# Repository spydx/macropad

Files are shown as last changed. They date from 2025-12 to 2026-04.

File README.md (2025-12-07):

# Macro Pad

This is a small macropad inspired by the Figma Pad from Worklouder Figma Creator.

## v1.1

The first version, I did some mistakes and are not entirely happy with it. I managed to wire the OLED wrong, and are not happy with the placement of the microcontroller.

v1.1 contains fixes for:

- OLED Wiring (mixed up SDA & SCL signal)
- Flipped Diode (only on the board)

If you wanna build it, you can follow the instructions in the [README](v1.1/README.md)

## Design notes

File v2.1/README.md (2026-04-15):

# Macropad v1.1

My first attempt on build a 14 key macropad with two rotary encoders.

Read everything first, this is a very thin guide of what you need, the rest you are on your own.

## What you need

| Count | Component | Link |
| ---- | --- | --- |
|  1 | PCB | JLCPCB or any other |
|  1 | WaveShare RP2040-Zero USB-C| [WaveShare](https://www.waveshare.com/rp2040-zero.htm?sku=20335) |
| 14 | 1N4148 Diodes | [Mouser](https://no.mouser.com/ProductDetail/onsemi-Fairchild/1N4148?qs=i4Fj9T%2FoRm8RMUhj5DeFQg%3D%3D) |
| 12 | Kailh Choc V2 Low Profiles Keys | [Max Gamming](https://www.maxgaming.no/no/switchar/choc-v2-low-profile-brown) |
|  2 | Rotary Encoderss PEC12R-2120F-S0012 | [Mouser](https://no.mouser.com/ProductDetail/Bourns/PEC12R-2120F-S0012?qs=Zq5ylnUbLm4y5zPMmL%252Bc3g%3D%3D) |
|  1 | OLED 128x32 SSD1306 I2C | [Amazon](https://www.amazon.com/128x32-SSD1306-Consumption-Display-Arduino/dp/B07PDFCVXL) |

Notes.. if you buy other parts than these they might not be compatible, inspect the schematics for details if the components will fit.

You will need knobs for the encoders and keycaps, see 3D print section.

## PCB

The [PCB](PCB/production/BouvetMacroPad-Rev2.1.zip) can be used to produce the new Rev 2.1 version of the macropad.

You can get PCBs printed from PCBWay or any other.

## Soldering

Recommended soldering order

- Diodes
- Microcontroller
- Switches
- Rotary Encoders
- OLED

## 3D printed Parts

### Keycaps and Knobs

Keycaps are not mentioned here, but you will need Low Profile Keycaps that fit the Kailh Choc V2.
There are many available to be 3D printed. E.g. the following will fit: [Keycaps](https://makerworld.com/en/models/1152559-choc-v2-ultra-thin-keycaps#profileId-1156967)

Rotary encoder knobs are also needed e.g. [these](https://makerworld.com/en/models/154058-grippy-encoder-knob?from=search#profileId-169689)

### Case

There is a small case, designed by Vilde Holtet, in the [CAD](CAD) folder.

There is a STEP file of the PCB that you can use to aid the design a new case in e.g. FreeCAD.

No special setting, when printing

## QMK Firmware

This keyboard uses QMK, until the my PR has been accepted, you need to follow these special steps.

You need to download MY fork of the repository, and checkout the custom branch `custom-keyboards`.
This contains the handwired keyboard config for the macropad.

```shell
git clone https://github.com/spydx/qmk_firmware
cd qmk_firmware
git checkout bouvetv2

# Ensure that this folder is the QMK homedir
qmk config user.qmk_home=<pwd of your folder> 
qmk config user.keyboard=handwired/bouvet/macropad/v2
qmk config user.keymap=default
```

Once this is you can compile and flash the macropad.

```shell
qmk compile

# While connecting the macro pad, press and hold the top LEFT button until the macropad is detected
qmk flash 
```

Ready to use

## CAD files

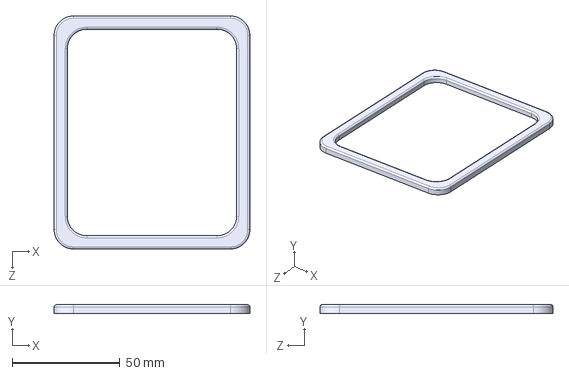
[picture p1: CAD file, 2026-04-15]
v2.1/CAD/Topp (kun frame).STEP
91.0 x 4.00 x 108.3 mm

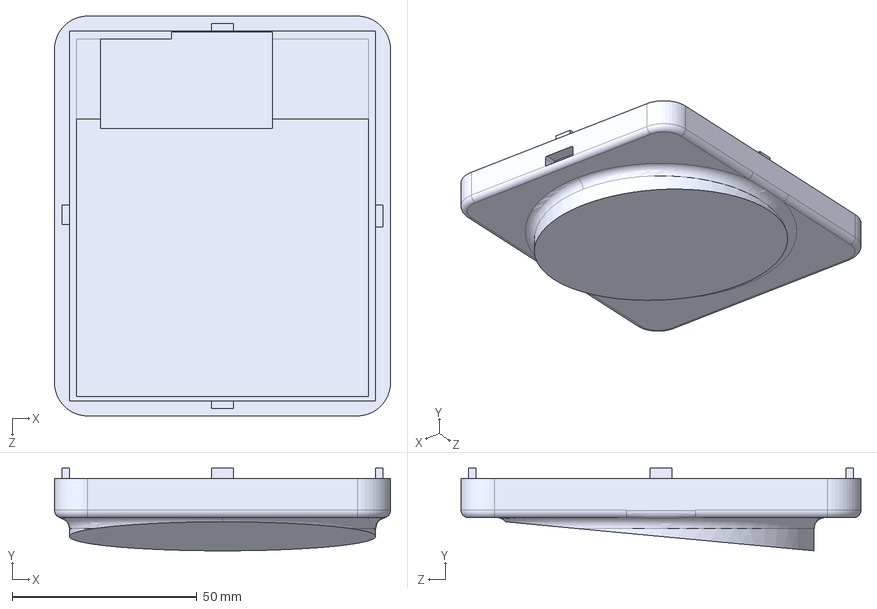
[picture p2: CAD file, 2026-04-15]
v2.1/CAD/Base.STEP
91.0 x 22.4 x 108.3 mm

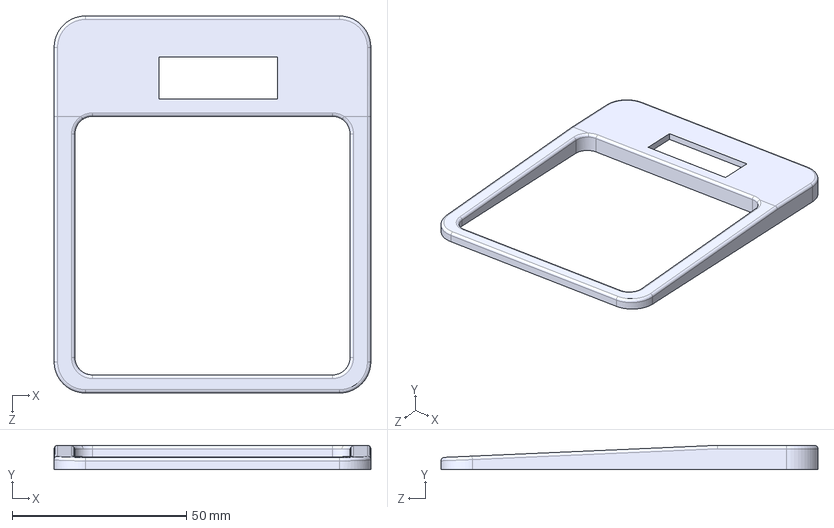
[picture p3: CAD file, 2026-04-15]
v2.1/CAD/Topp (m_ slot for skjerm).STEP
91.0 x 7.00 x 108.3 mm

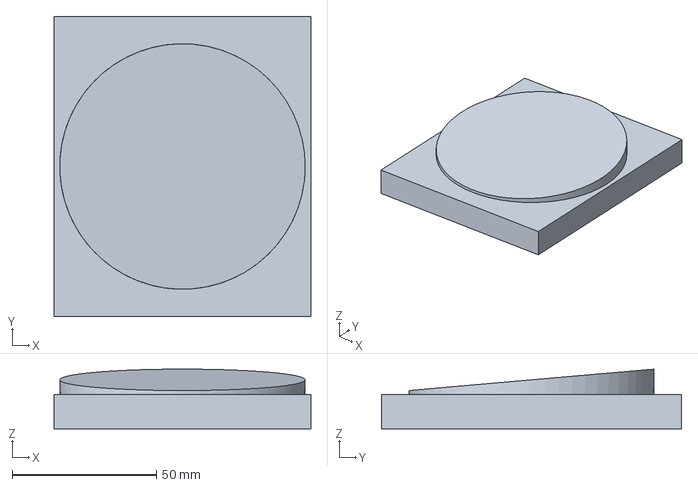
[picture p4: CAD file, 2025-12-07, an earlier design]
v1.1/Cad/MacroPadCase.FCStd
89.0 x 104.0 x 20.7 mm

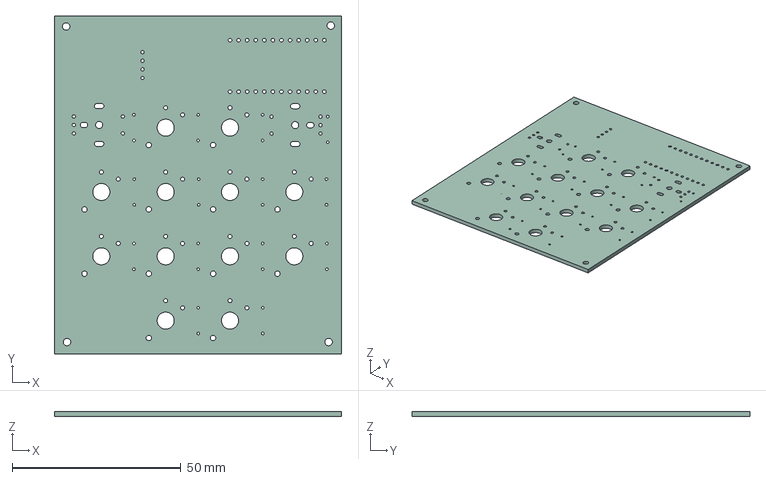
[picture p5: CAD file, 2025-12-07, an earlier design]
v1.1/Cad/Figma_KeyPad_PCB.step
85.0 x 100.0 x 1.51 mm

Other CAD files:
v1.1/Cad/MacroPadCase.stl

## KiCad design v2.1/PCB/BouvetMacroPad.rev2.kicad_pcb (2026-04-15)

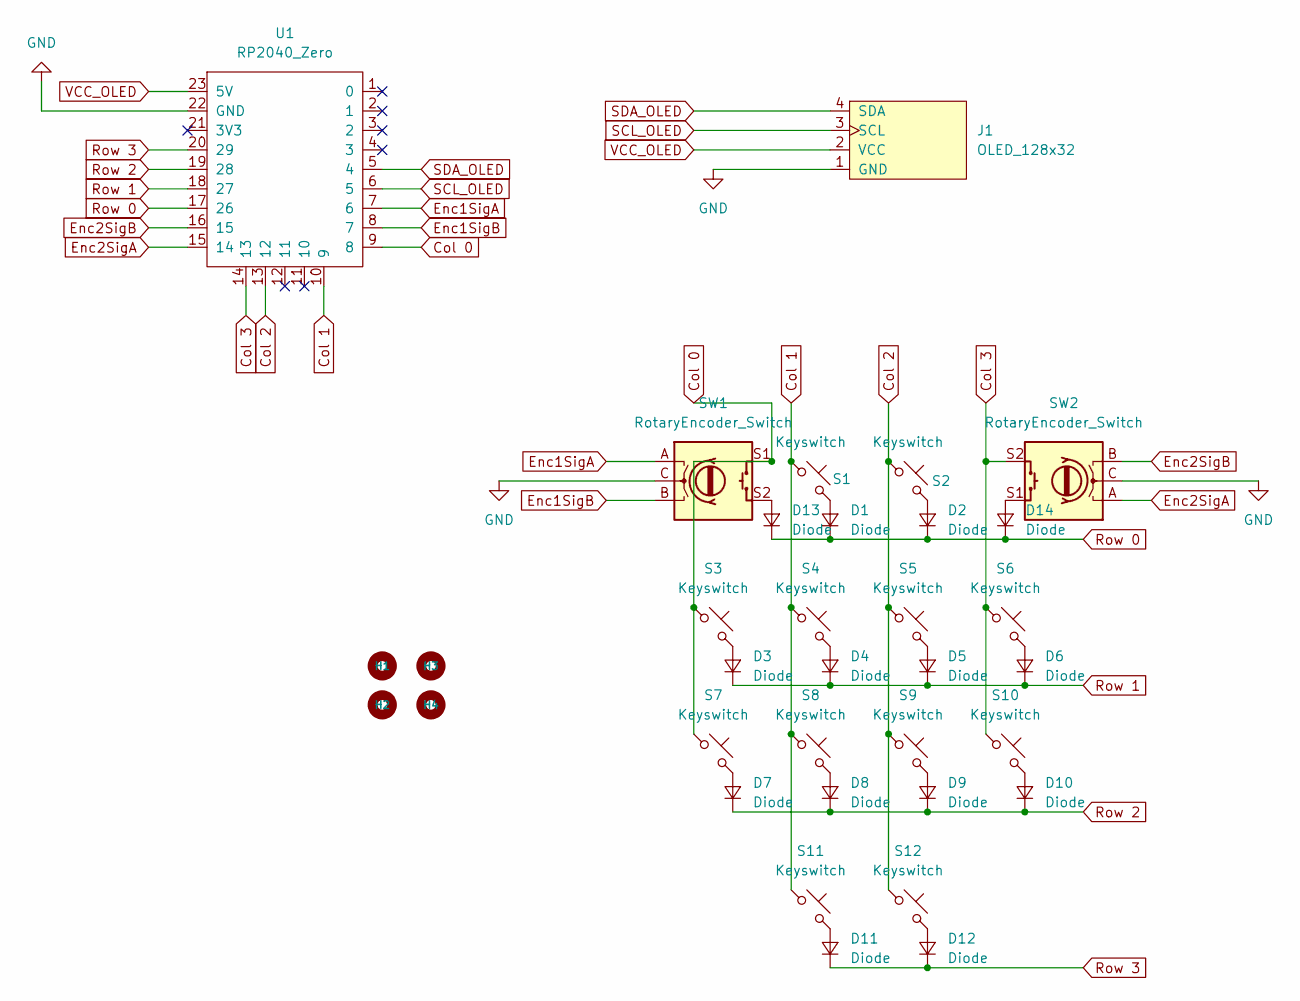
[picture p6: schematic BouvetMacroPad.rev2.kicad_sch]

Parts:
D1, D2, D3, D4, D5, D6, D7, D8, D9, D10, D11, D12, D13, D14: Diode; Diode_DO-35
H1, H2, H3, H4: MountingHole_5mm
J1: OLED_128x32
S1, S2, S3, S4, S5, S6, S7, S8, S9, S10, S11, S12: Keyswitch; Choc_V2_1.00u
SW1, SW2: RotaryEncoder_Switch; RotaryEncoder_Alps_EC11E-Switch_Vertical_H20mm_MountingHoles
U1: RP2040_Zero

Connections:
Col 0: S3.1, S7.1, SW1.S1, U1.9 (8)
Col 1: S1.1, S4.1, S8.1, S11.1, U1.10 (9)
Col 2: S2.1, S5.1, S9.1, S12.1, U1.13 (12)
Col 3: S6.1, S10.1, SW2.S2, U1.14 (13)
Enc1SigA: SW1.A, U1.7 (6)
Enc1SigB: SW1.B, U1.8 (7)
Enc2SigA: SW2.A, U1.15 (14)
Enc2SigB: SW2.B, U1.16 (15)
GND: J1.1 (GND), SW1.C, SW2.C, U1.22 (GND)
unnamed: D1.2 (A), S1.2
unnamed: D2.2 (A), S2.2
unnamed: D3.2 (A), S3.2
unnamed: D4.2 (A), S4.2
unnamed: D5.2 (A), S5.2
unnamed: D6.2 (A), S6.2
unnamed: D7.2 (A), S7.2
unnamed: D8.2 (A), S8.2
unnamed: D9.2 (A), S9.2
unnamed: D10.2 (A), S10.2
unnamed: D11.2 (A), S11.2
unnamed: D12.2 (A), S12.2
unnamed: D13.2 (A), SW1.S2
unnamed: D14.2 (A), SW2.S1
Row 0: D1.1 (K), D2.1 (K), D13.1 (K), D14.1 (K), U1.17 (26)
Row 1: D3.1 (K), D4.1 (K), D5.1 (K), D6.1 (K), U1.18 (27)
Row 2: D7.1 (K), D8.1 (K), D9.1 (K), D10.1 (K), U1.19 (28)
Row 3: D11.1 (K), D12.1 (K), U1.20 (29)
SCL_OLED: J1.3 (SCL), U1.6 (5)
SDA_OLED: J1.4 (SDA), U1.5 (4)
VCC_OLED: J1.2 (VCC), U1.23 (5V)

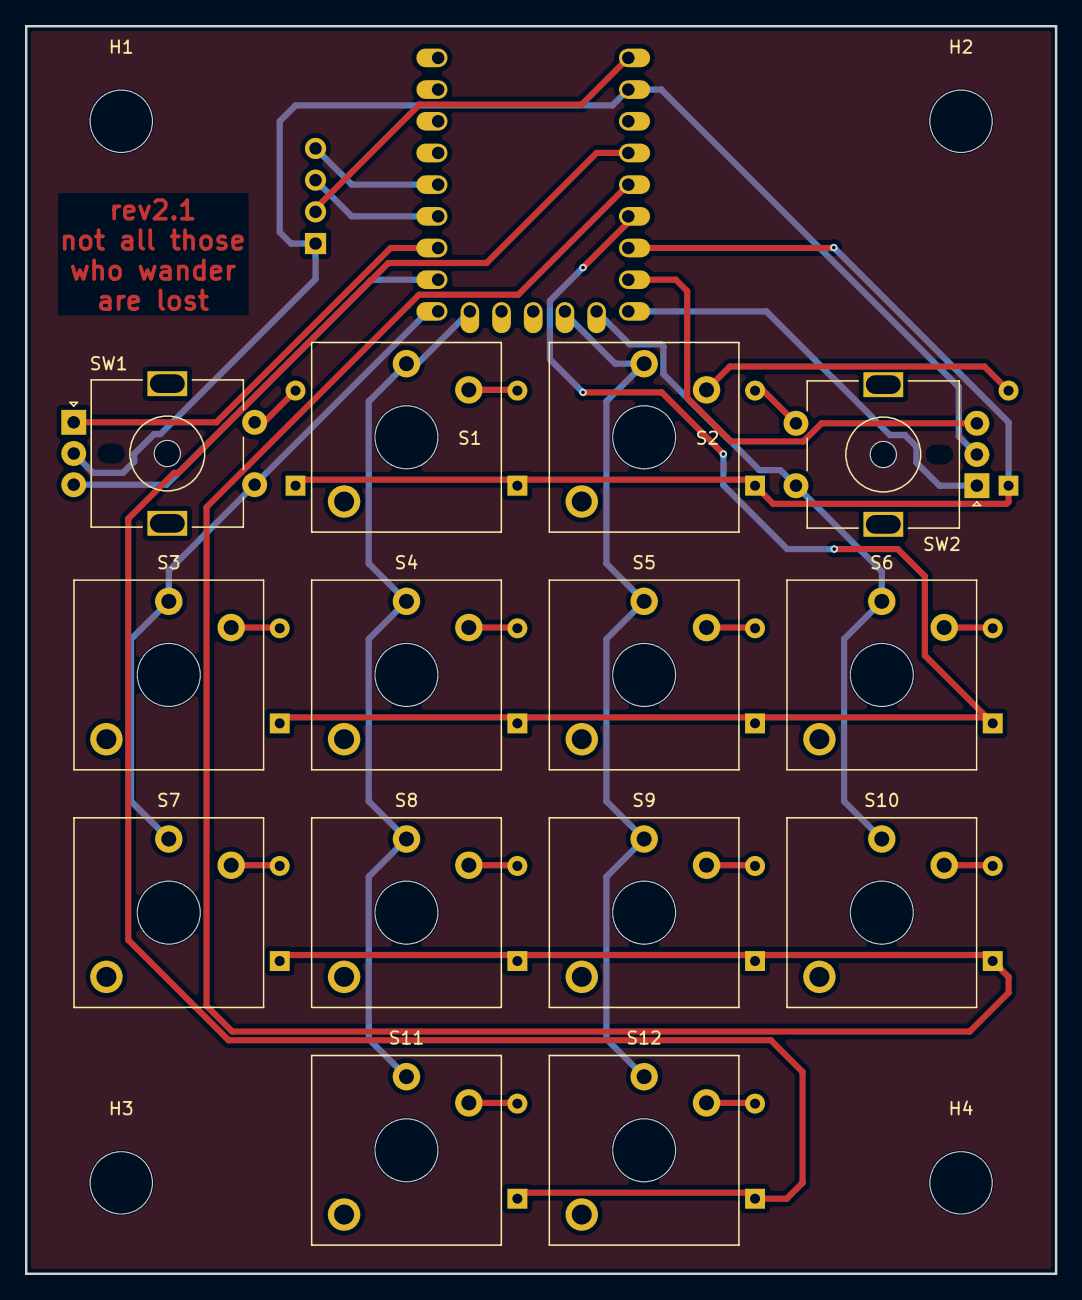
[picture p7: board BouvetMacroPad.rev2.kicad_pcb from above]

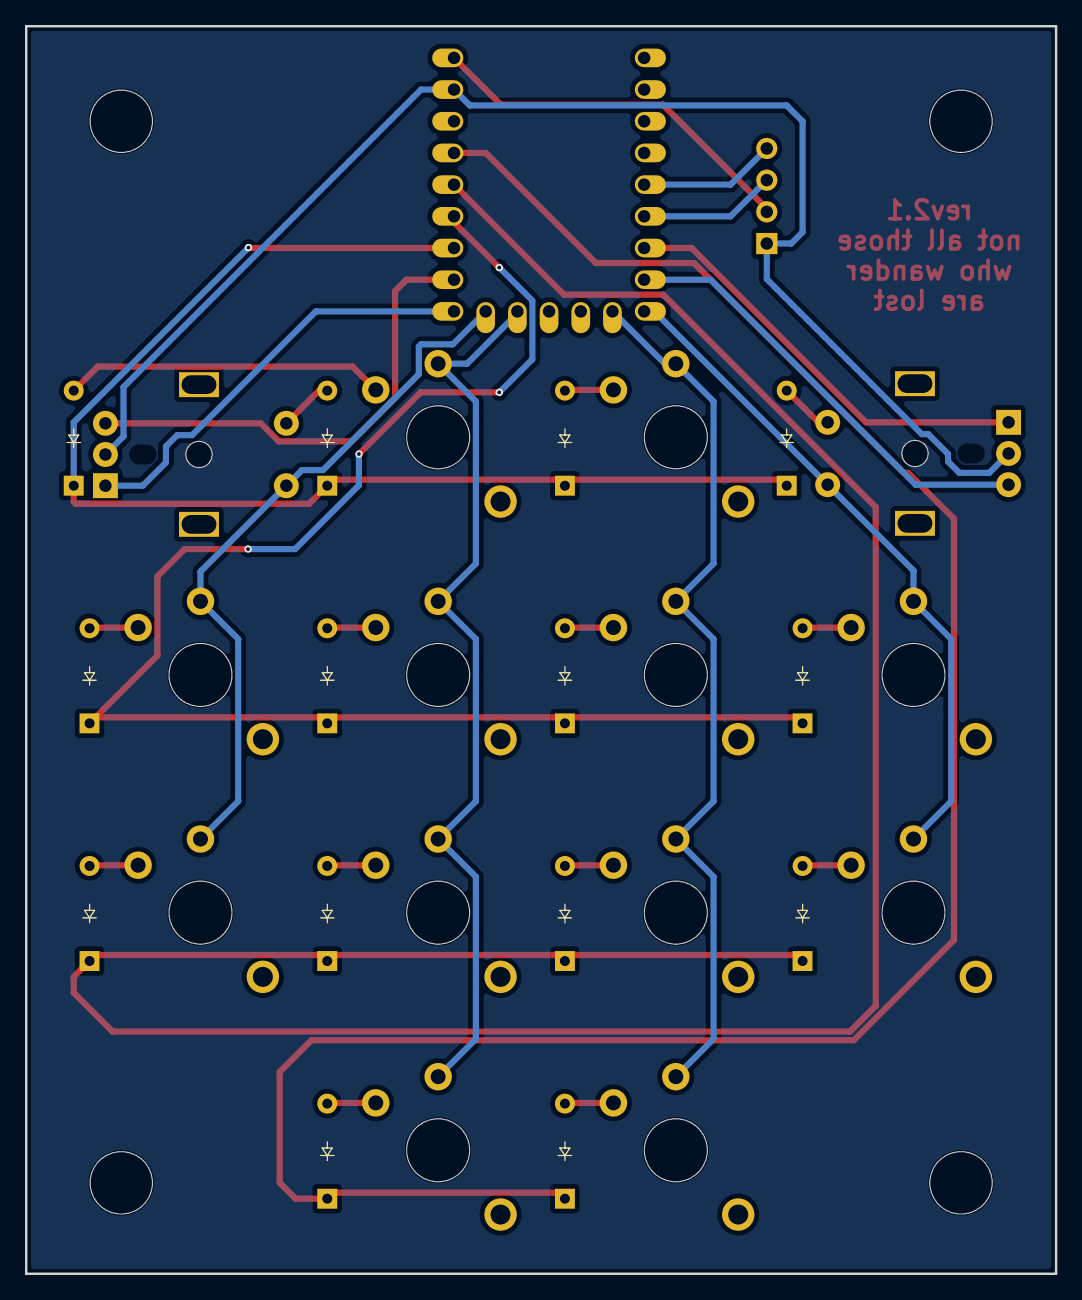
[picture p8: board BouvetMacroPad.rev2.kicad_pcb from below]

Board: 2 copper layers, 82.5 x 100.0 mm, 34 parts (15 on the bottom side), 30 nets.

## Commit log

2025-12-07 Rev 1.1
    [Figma_KeyPad_PCB.kicad_pcb, Figma_KeyPad_PCB.kicad_sch, Figma_KeyPad_PCB.step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]
2026-04-15 MacroPad v2.1
    [Base.STEP, BouvetMacroPad.rev2.kicad_pcb, BouvetMacroPad.rev2.kicad_sch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]
